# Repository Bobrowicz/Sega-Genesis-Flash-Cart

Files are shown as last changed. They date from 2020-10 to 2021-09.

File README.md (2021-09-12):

# Sega Genesis Flash Cartridge
 This project is an attempt to create programmable cartridge for Sega Genesis system.  Project is based around two SST39SF040 4Mbit flash chips. Address bus is common to both chips, and data bus is split between the two into low and high byte.  Three position switch allows user to slelect between two 512kB banks or use entire 1MB capacity.
 
 Project has not been tested in real hardware.

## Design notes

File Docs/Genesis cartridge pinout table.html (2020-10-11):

# Sega Genesis Cartridge Pinout Data

A1       Console back        A32
================================
B1       Console front       B32

## Side A

Pin | Direction | Designation | Description
A1 | Output | GND
A2 | Output | +5V
A3 | Output | Address Bit 8
A4 | Output | Address Bit 11
A5 | Output | Address Bit 7
A6 | Output | Address Bit 12
A7 | Output | Address Bit 6
A8 | Output | Address Bit 13
A9 | Output | Address Bit 5
A10 | Output | Address Bit 14
A11 | Output | Address Bit 4
A12 | Output | Address Bit 15
A13 | Output | Address Bit 3
A14 | Output | Address Bit 16
A15 | Output | Address Bit 2
A16 | Output | Address Bit 17
A17 | Output | Address Bit 1 | This is the first address bit, bit 0 is hardwired to low.
A18 | Output | GND
A19 | Output / Input | Data Bit 7
A20 | Output / Input | Data Bit 0
A21 | Output / Input | Data Bit 8
A22 | Output / Input | Data Bit 6
A23 | Output / Input | Data Bit 1
A24 | Output / Input | Data Bit 9
A25 | Output / Input | Data Bit 5
A26 | Output / Input | Data Bit 2
A27 | Output / Input | Data Bit 10
A28 | Output / Input | Data Bit 4
A29 | Output / Input | Data Bit 3
A30 | Output / Input | Data Bit 11
A31 | Output | +5V
A32 | Output | GND

## Side B

Pin | Direction | Designation | Description
B1 | Input | Left Audio | Audio sourced from cartridge, left channel, mixed into output.
B2 | Output | /MRES | Master reset, from system start up.
B3 | Input | Right Audio | Audio sourced from cartridge, right channel, mixed into output.
B4 | Output | Address Bit 9
B5 | Output | Address Bit 10
B6 | Output | Address Bit 18
B7 | Output | Address Bit 19
B8 | Output | Address Bit 20
B9 | Output | Address Bit 21
B10 | Output | Address Bit 22
B11 | Output | Address Bit 23
B12 | Output | /YS | VDP is currently drawing the backdrop colour.
B13 | Output | /VSYNC | Vertical sync pulse.
B14 | Output | /HSYNC | Horizonal sync pulse.
B15 | Output | EDCLK | External Dot Clock (~13.4 or 10.7 MHz).
B16 | Output | /CAS0 | Read or Write on $000000-$DFFFFF region.
B17 | Output | /CEO | Chip Enable for the cartridge. Normally low when accessing $000000-$3FFFFF region. When expension unit is present then low when accessing $400000-$7FFFFF.
B18 | Output | /AS | Address strobe, address on bus is currently valid and not changing.
B19 | Output / Input | VCLK | 68K Clock
B20 | Output / Input | /DTACK | Data acknowledge to 68K.
B21 | Output / Input | /CAS2 | Read or Write on $E00000-$FFFFFF region, maybe (Upper 2MB).
B22 | Output / Input | Data Bit 15
B23 | Output / Input | Data Bit 14
B24 | Output / Input | Data Bit 13
B25 | Output / Input | Data Bit 12
B26 | Output / Input | /ASEL | Read or Write on $000000-$7FFFFF region.
B27 | Output | /VRES | System reset, from front panel switch.
B28 | Output | /LWR | Lower byte WRite, the lower byte on the data lines should be written to the location in the address lines.
B29 | Output | /UWR | Upper byte WRite, the upper byte on the data lines should be written to the location in the address lines.
B30 | Input | /M3 | Pulled high in console, cartridge shorts to ground to indicate console should run in Mark 3 (Master System) mode.
B31 | Output | /TIME | Set for r/w at/to $A13000-$A130FF, given the name suggests it might be for a real time clock in the cartridge. This would enable usage as a chip enable on a RTC, using fewer address lines or logic to that RTC. Used in Sonic 3 for SRAM.
B32 | Input | /CART | Pulled high in console, cartridge shorts to ground to indicate presence.

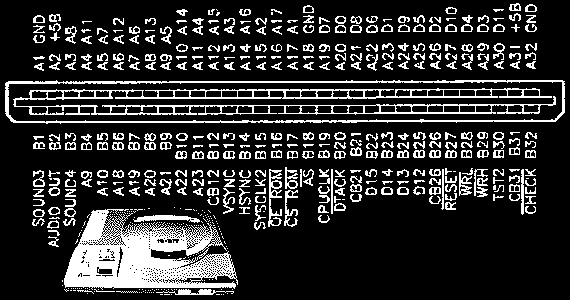
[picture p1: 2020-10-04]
Docs/SEGACartSlot.gif

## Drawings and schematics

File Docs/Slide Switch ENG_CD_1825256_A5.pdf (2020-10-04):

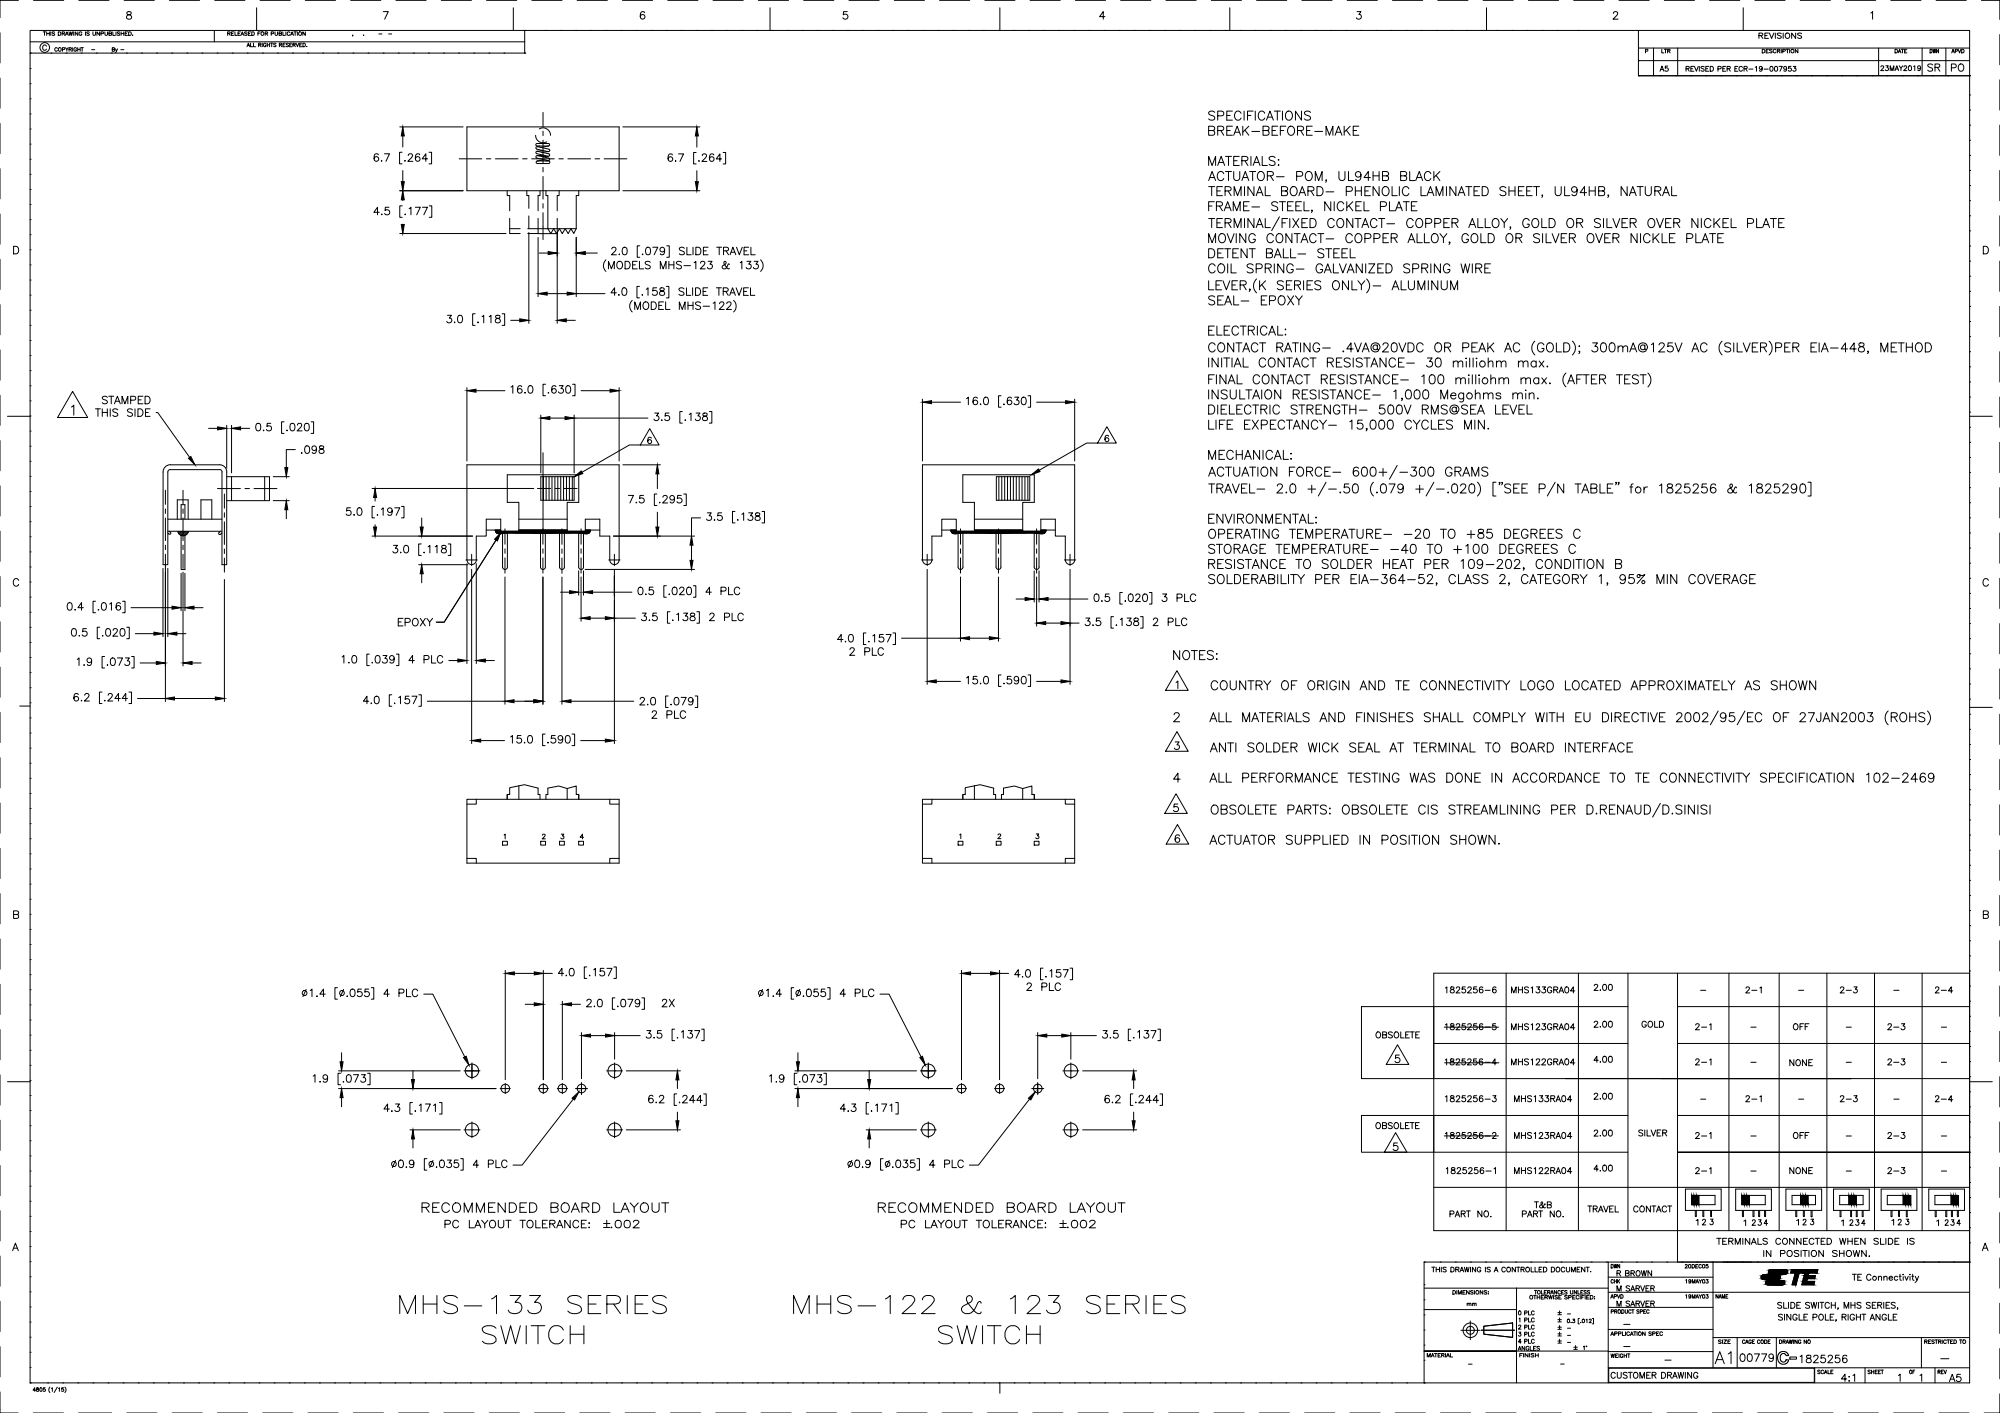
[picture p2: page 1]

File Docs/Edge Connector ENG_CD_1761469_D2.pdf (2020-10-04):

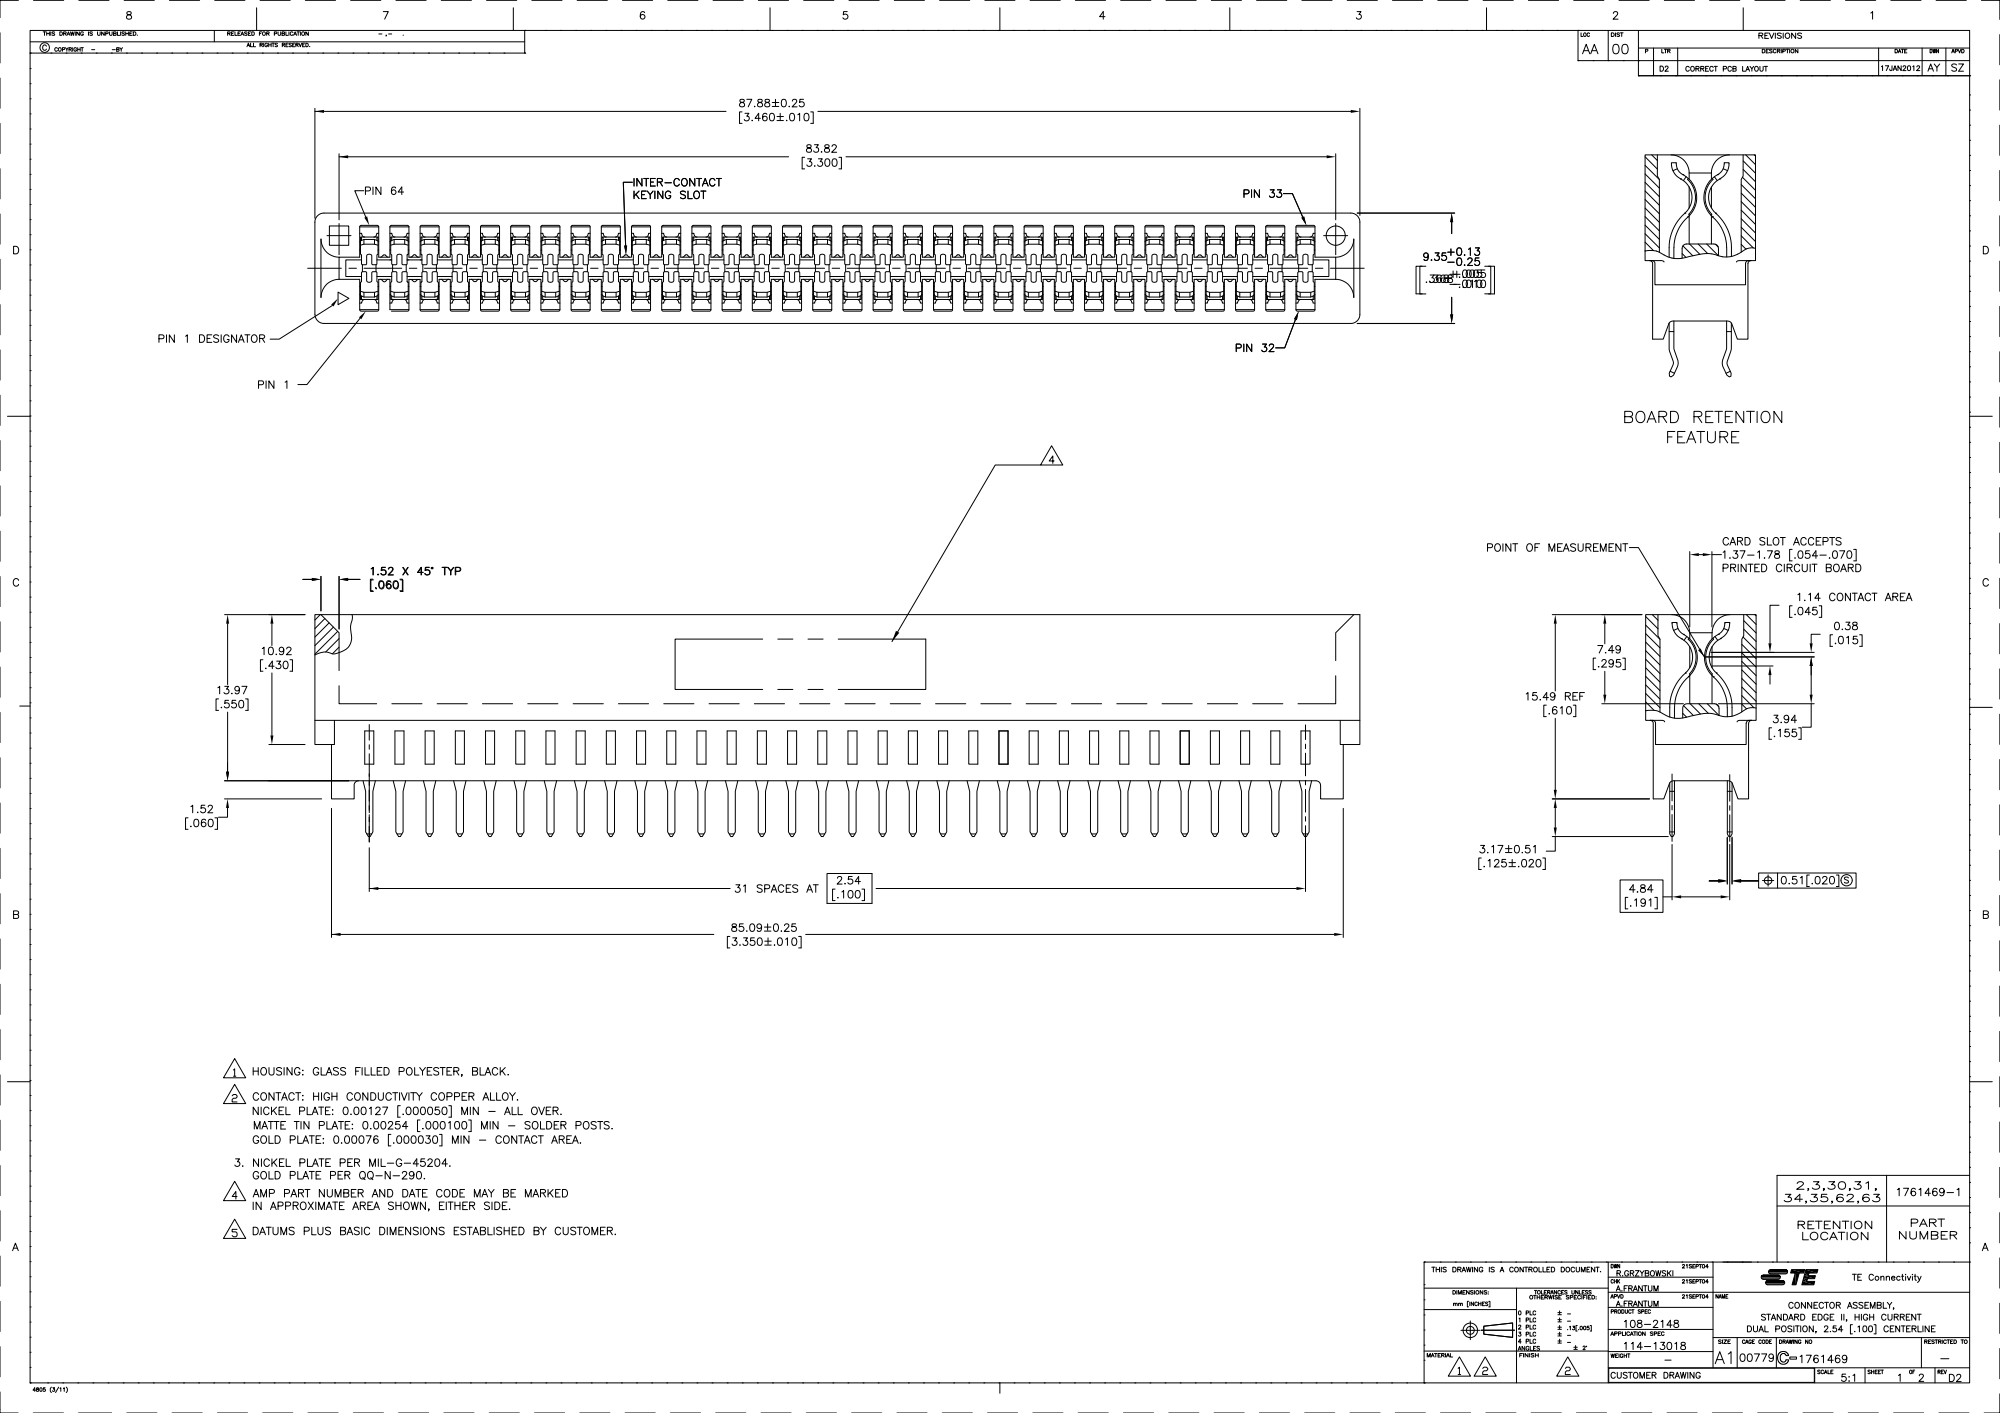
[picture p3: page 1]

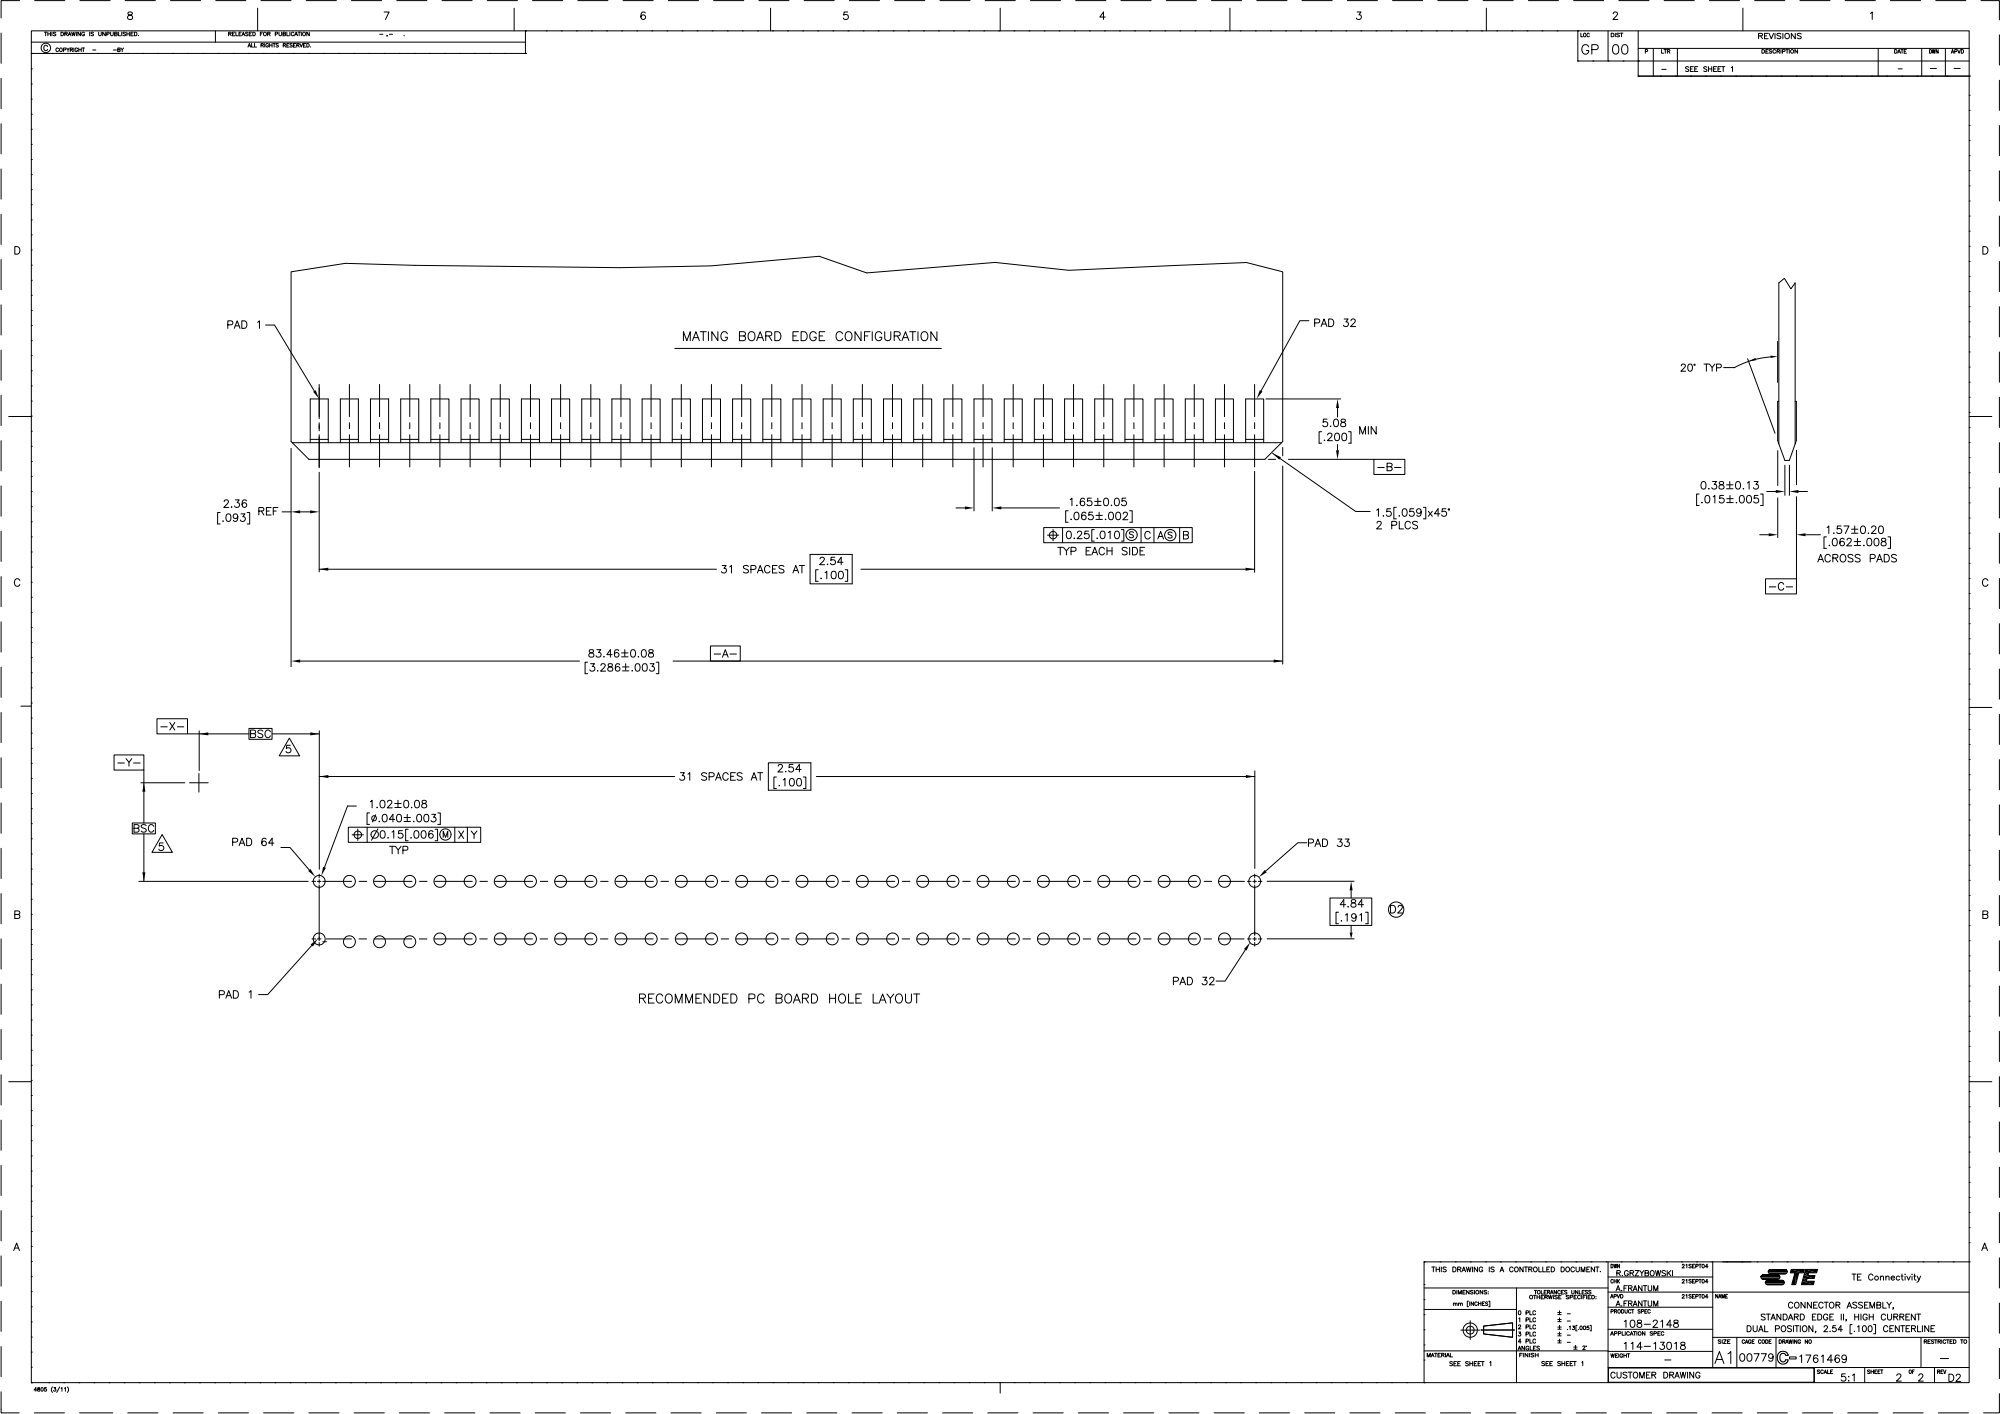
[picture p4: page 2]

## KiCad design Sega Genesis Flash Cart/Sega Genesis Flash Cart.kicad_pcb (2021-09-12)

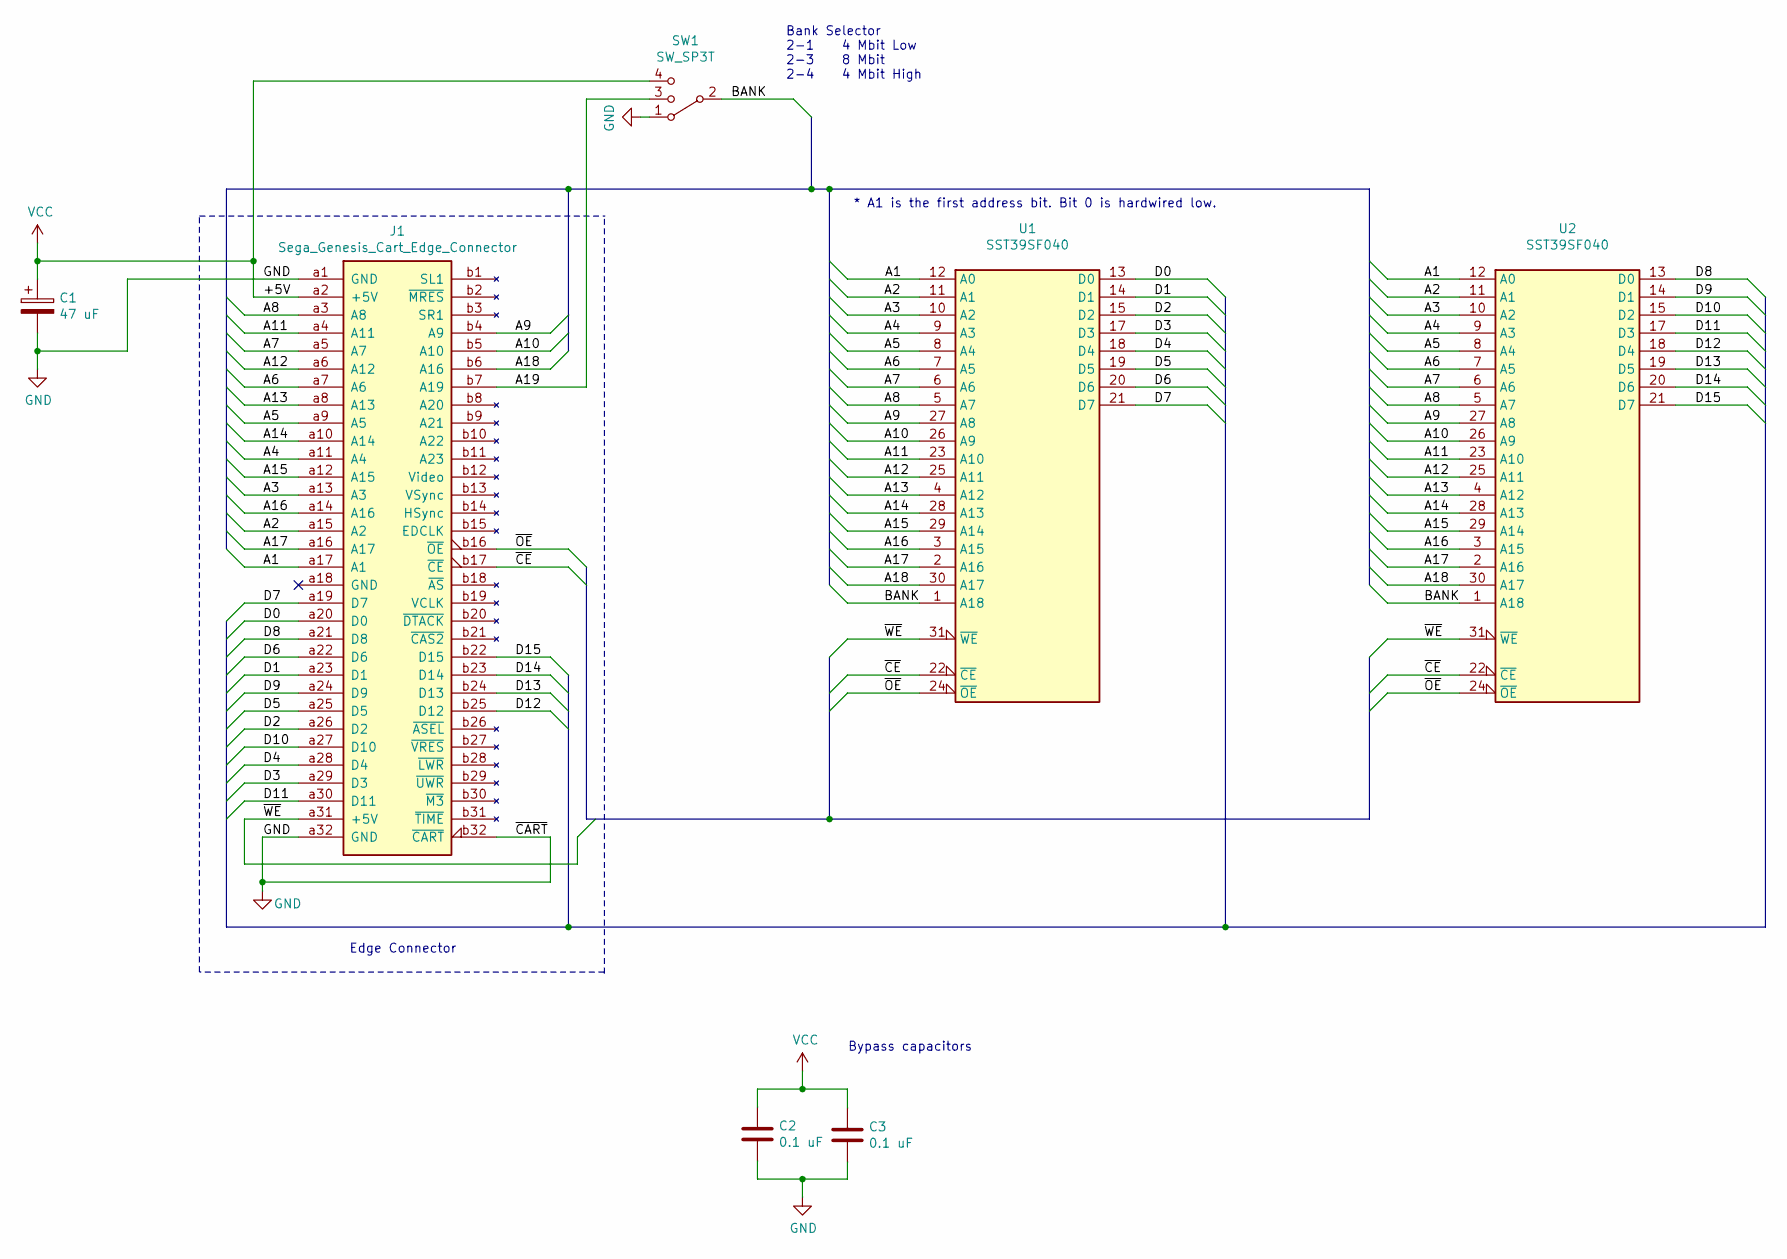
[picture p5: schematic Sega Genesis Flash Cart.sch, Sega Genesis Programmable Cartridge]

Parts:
C1: 47 uF; CP_Radial_D6.3mm_P2.50mm
C2, C3: 0.1 uF; C_Disc_D4.3mm_W1.9mm_P5.00mm
J1: Sega_Genesis_Cart_Edge_Connector; GENESIS-EDGE
SW1: SW_SP3T; MHS_133_Series_Switch
U1, U2: SST39SF040; DIP-32_W15.24mm

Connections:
/A1: J1.a17 (A1), U1.12 (A0), U2.12 (A0)
/A2: J1.a15 (A2), U1.11 (A1), U2.11 (A1)
/A3: J1.a13 (A3), U1.10 (A2), U2.10 (A2)
/A4: J1.a11 (A4), U1.9 (A3), U2.9 (A3)
/A5: J1.a9 (A5), U1.8 (A4), U2.8 (A4)
/A6: J1.a7 (A6), U1.7 (A5), U2.7 (A5)
/A7: J1.a5 (A7), U1.6 (A6), U2.6 (A6)
/A8: J1.a3 (A8), U1.5 (A7), U2.5 (A7)
/A9: J1.b4 (A9), U1.27 (A8), U2.27 (A8)
/A10: J1.b5 (A10), U1.26 (A9), U2.26 (A9)
/A11: J1.a4 (A11), U1.23 (A10), U2.23 (A10)
/A12: J1.a6 (A12), U1.25 (A11), U2.25 (A11)
/A13: J1.a8 (A13), U1.4 (A12), U2.4 (A12)
/A14: J1.a10 (A14), U1.28 (A13), U2.28 (A13)
/A15: J1.a12 (A15), U1.29 (A14), U2.29 (A14)
/A16: J1.a14 (A16), U1.3 (A15), U2.3 (A15)
/A17: J1.a16 (A17), U1.2 (A16), U2.2 (A16)
/A18: J1.b6 (A16), U1.30 (A17), U2.30 (A17)
/A19: J1.b7 (A19), SW1.3
/BANK: SW1.2, U1.1 (A18), U2.1 (A18)
/D0: J1.a20 (D0), U1.13 (D0)
/D1: J1.a23 (D1), U1.14 (D1)
/D2: J1.a26 (D2), U1.15 (D2)
/D3: J1.a29 (D3), U1.17 (D3)
/D4: J1.a28 (D4), U1.18 (D4)
/D5: J1.a25 (D5), U1.19 (D5)
/D6: J1.a22 (D6), U1.20 (D6)
/D7: J1.a19 (D7), U1.21 (D7)
/D8: J1.a21 (D8), U2.13 (D0)
/D9: J1.a24 (D9), U2.14 (D1)
/D10: J1.a27 (D10), U2.15 (D2)
/D11: J1.a30 (D11), U2.17 (D3)
/D12: J1.b25 (D12), U2.18 (D4)
/D13: J1.b24 (D13), U2.19 (D5)
/D14: J1.b23 (D14), U2.20 (D6)
/D15: J1.b22 (D15), U2.21 (D7)
/~CE: J1.b17 (~CE), U1.22 (~CE), U2.22 (~CE)
/~OE: J1.b16 (~OE), U1.24 (~OE), U2.24 (~OE)
/~WE: J1.a31 (+5V), U1.31 (~WE), U2.31 (~WE)
GND: C1.2, C2.2, C3.2, J1.a1 (GND), J1.a32 (GND), J1.b32 (~CART), SW1.1, U1.16 (GND), U2.16 (GND)
VCC: C1.1, C2.1, C3.1, J1.a2 (+5V), SW1.4, U1.32 (VCC), U2.32 (VCC)

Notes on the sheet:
Edge Connector
* A1 is the first address bit. Bit 0 is hardwired low.
Bypass capacitors
Bank Selector 2-1 4 Mbit Low 2-3 8 Mbit 2-4 4 Mbit High

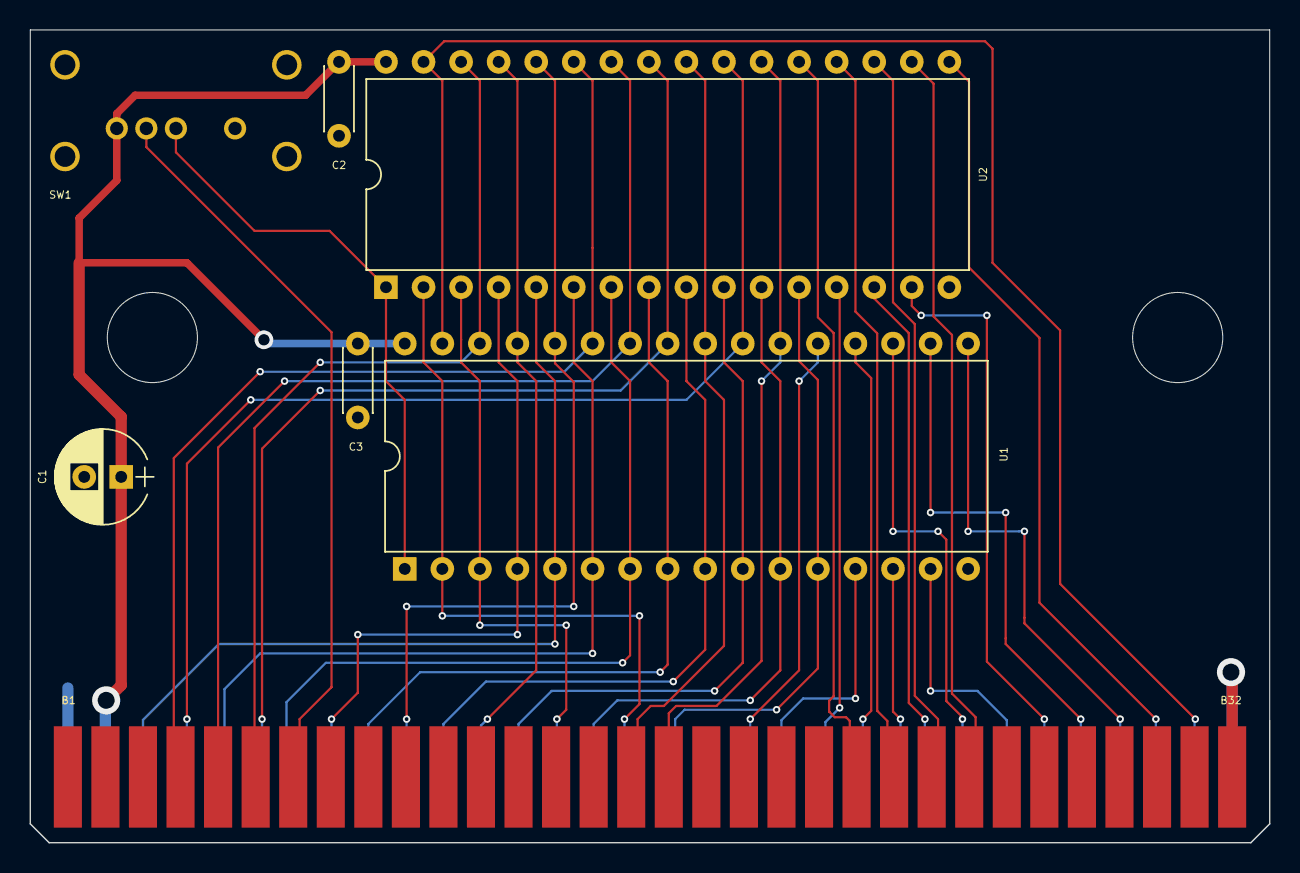
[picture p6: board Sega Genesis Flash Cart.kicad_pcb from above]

Board: 2 copper layers, 83.8 x 55.0 mm, 7 parts (0 on the bottom side), 41 nets.

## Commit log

2020-10-04 Project start
    Gathered some documentation and started on cartridge schematic.
    [Sega Genesis Cartridge.kicad_pcb, Sega Genesis Cartridge.sch]
2020-10-04 Circuit schematic rev A
    [Sega Genesis Cartridge.sch]
2020-10-04 Capacitor values
    [Sega Genesis Cartridge.sch]
2020-10-11 Begin PCB layout
    Revised schematic, added footprints and strated PCB layout.
    [Sega Genesis Cartridge.sch]
2021-02-20 PCB layout
    [Sega Genesis Cartridge.kicad_pcb]
2021-09-12 Revised PCB and schematic
    Changed schematic symbol for Genesis edge connector.
    Changed footprint for Genesis edge connector. Ripped all traces and re-routed the PCB.
    [Sega Genesis Cartridge.kicad_pcb, Sega Genesis Flash Cart.kicad_pcb, Sega Genesis Flash Cart.sch]
